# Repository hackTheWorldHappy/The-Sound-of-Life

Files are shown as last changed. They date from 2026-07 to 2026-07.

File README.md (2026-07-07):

# The Sound of Life 
janky_readmefalloutpic

A portable theremin using two time of flight sensors (ToFs) to detect pitch and volume. Also has a 1.8 TFT, which displays your live hand position relative to the sensors in order to make it easier to locate the proper pitch/volume.  

## CAD 
The stls can be found in the "CAD" folder of the repo, while the source files are publicly available at [this Onshape link](https://cad.onshape.com/documents/89ee755f4b78b4ae9f984f04/w/80025889893a9b576d4bea7a/e/b41170ff59c016846a22fa0f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).

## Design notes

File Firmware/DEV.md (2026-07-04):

because of bad network you need to increase network timeout:
C:\Users\<USER  >\.arduinoIDE\arduino-cli.yaml

add this:
network:
  connection_timeout: 300s

---

using Arduino and this board manager:

https://github.com/earlephilhower/arduino-pico/releases/download/global/package_rp2040_index.json

install libs

Tools > Usb Stack
use Adafruit one

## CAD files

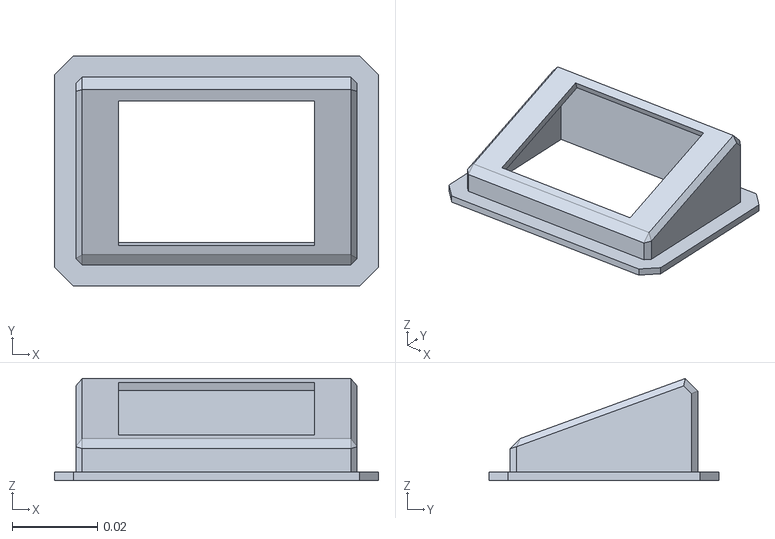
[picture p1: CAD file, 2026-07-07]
CAD/oled_cover.stl
0.076 x 0.054 x 0.0239

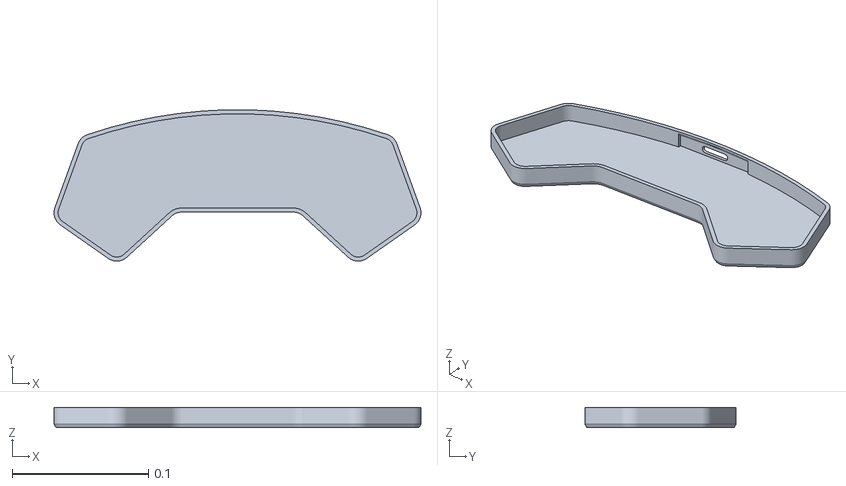
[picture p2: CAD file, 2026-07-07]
CAD/case_top.stl
0.269 x 0.111 x 0.015

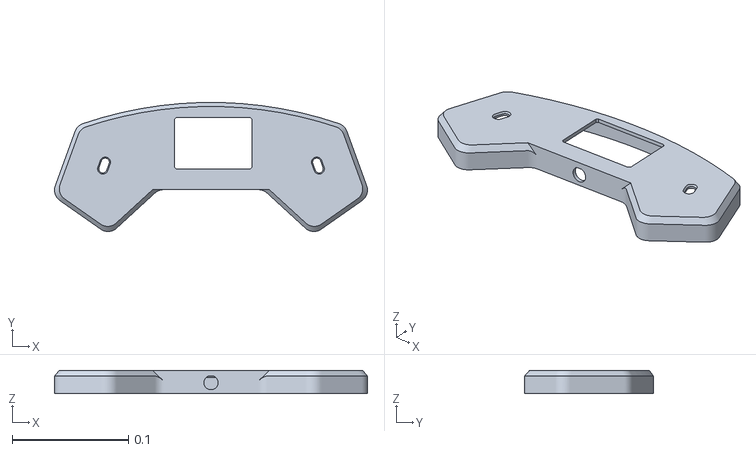
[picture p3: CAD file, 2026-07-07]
CAD/case_bottom.stl
0.269 x 0.111 x 0.02

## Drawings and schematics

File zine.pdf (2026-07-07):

# THE SOUND OF LIFE

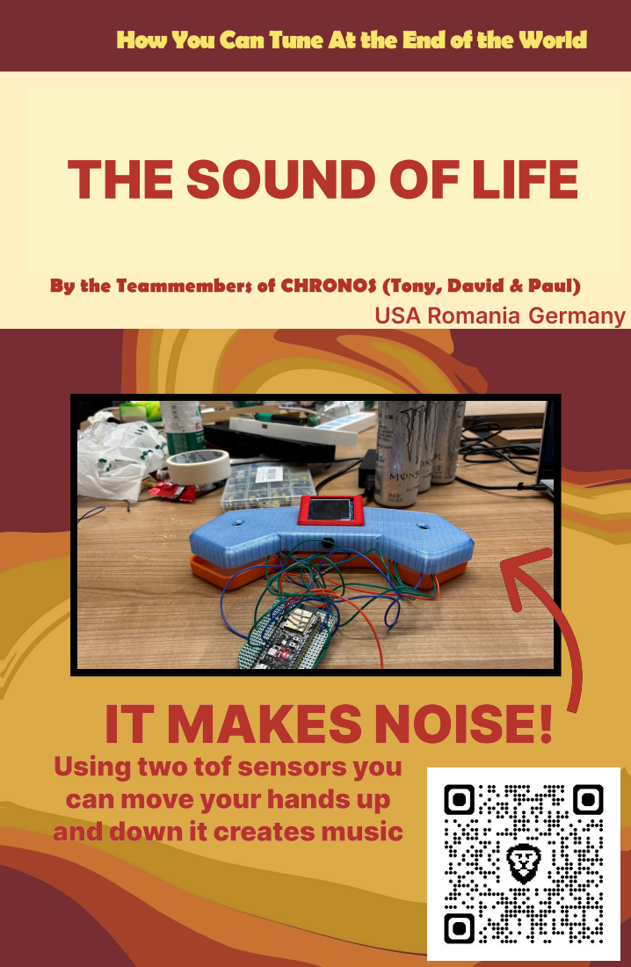
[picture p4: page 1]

USA Romania Germany

IT MAKES NOISE!
Using two tof sensors you
can move your hands up
and down it creates music

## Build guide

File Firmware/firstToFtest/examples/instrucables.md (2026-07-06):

his is a DIY project to create a MIDI Theremin . So lets go....
Supplies
Supplies
Supplies
Supplies

Arduino Leonardo

TOF sensor VL53LOX(2)

Berch pins(8)

Jumper wires

Micro USB cable
Step 1: WHY LEONARDO AND VL530LOX SENSOR
WHY LEONARDO AND VL530LOX SENSOR
WHY LEONARDO AND VL530LOX SENSOR

MIDI (Musical Instrument Digital Interface) devices are electronic instruments, controllers, and hardware that communicate musical performance data using the MIDI protocol (introduced in 1983). Instead of sending audio, MIDI sends digital instructions that describe music (e.g., notes, velocity, pitch bends, control changes).

The Arduino Leonardo is a microcontroller board based on the ATmega32u4. Unlike many other Arduino boards, it has built-in USB communication, allowing it to appear to a computer as a keyboard, mouse, or MIDI device without extra hardware. It features 20 digital I/O pins, 12 analog inputs, PWM outputs, a 16 MHz clock, and can be powered via USB or an external supply.

The reason for choosing VL530LOX Sensor are:

The VL53L0X time-of-flight distance sensor is far more suitable for building a theremin than traditional ultrasonic sensors because of its precision, speed, and stability. It measures distance using a tiny laser pulse, giving it millimeter-level accuracy and smooth, consistent readings. This is critical in a theremin, where even small fluctuations in distance translate into noticeable changes in pitch.

In contrast, ultrasonic sensors often produce jittery or unstable outputs, with limited resolution (around 1 cm) and slower response times, which can result in choppy or unpleasant sound transitions. The VL53L0X also features a very narrow sensing cone, allowing it to detect just the player’s hand without being confused by nearby objects, whereas ultrasonic sensors have a wide cone that easily picks up unintended reflections. Additionally, the VL53L0X is less affected by environmental factors like temperature, humidity, or surface texture, making its performance far more reliable. n.

Step 2: Test Run
Test Run

Here we tested the working of the concept using one sensor .

The code :

#include <Wire.h>

#include <Adafruit_VL53L0X.h>

// Create sensor object

Adafruit_VL53L0X lox = Adafruit_VL53L0X();

void setup() {

Serial.begin(115200);

while (!Serial); // Wait for Serial Monitor to open

Serial.println("VL53L0X Single Sensor Test");

// Initialize I²C

Wire.begin();

// Try to start sensor

if (!lox.begin()) {

Serial.println("Failed to find VL53L0X sensor!");

while (1); // Stop here if not found

}

Serial.println("VL53L0X sensor ready!");

}

void loop() {

VL53L0X_RangingMeasurementData_t measure;

// Perform a measurement

lox.rangingTest(&measure, false);

if (measure.RangeStatus != 4) { // Phase failures have error code 4

Serial.print("Distance: ");

Serial.print(measure.RangeMilliMeter);

Serial.println(" mm");

} else {

Serial.println("Out of range");

}

delay(200);

}
Step 3: CIRCUIT MAKING
CIRCUIT MAKING

LEONARDO HAS ONLY I^2C CHANNEL SO WHEN CONNECTING TWO VL530LOX WOULD BE RECOGNIZED AS ONE SENSOR RATHER THAN TWO SEPARATE ONES.

SO TO SOLVE THIS ISSUE WE HAVE INITIALIZE BOTH THE SENSORS IN SEPARETELY SO THAT THEY COULD HAVE THEIR UNIQUE I^2C ID.THEREFORE, THEIR XSHUT PINS ARE CONNECTED TO PIN 7,8 RESPECTIVELY SO ONE COULD BE MOMENTARILY SHUT TO INITIALIZE THE OTHER ONE .
Step 4: Coding

CODE TO INITIALIZE TWO VL530LOX SENSOR :

pinMode(XSHUT1, OUTPUT);

pinMode(XSHUT2, OUTPUT);

// Reset both

digitalWrite(XSHUT1, LOW);

digitalWrite(XSHUT2, LOW);

delay(10);

// Init Pitch sensor

digitalWrite(XSHUT1, HIGH);

delay(10);

if (!sensorPitch.begin(0x30)) {

Serial.println("Failed to detect Pitch sensor");

while (1);

}

// Init CC sensor

digitalWrite(XSHUT2, HIGH);

delay(10);

if (!sensorCC.begin(0x31)) {

Serial.println("Failed to detect CC sensor");

while (1);

}

Serial.println("Two VL53L0X ready!");

}

CODE OF PITCH BEND FUNCTION :

// Pitch bend calculation

float semitoneOffset = ((float)(pitchDist - pitchCenterDist) / (maxDistPitch - minDistPitch)) * pitchBendRangeSemitones * 2;

semitoneOffset = constrain(semitoneOffset, -pitchBendRangeSemitones, pitchBendRangeSemitones);

int bendValue = (int)(semitoneOffset * (8192.0 / pitchBendRangeSemitones));

bendValue = constrain(bendValue, -8192, 8191);

sendPitchBend(bendValue, midiChannel);

Serial.print("Distance: "); Serial.print(pitchDist);

Serial.print(" mm | Bend: "); Serial.println(bendValue); 

Code:
leothermin.ino

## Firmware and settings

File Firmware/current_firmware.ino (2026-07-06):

#include <Arduino.h>
#include <Wire.h>
#include <Adafruit_VL53L0X.h>
#include <SPI.h>
#include <Adafruit_GFX.h>
#include <Adafruit_ST7735.h>
#include <math.h>

// -------------------- PINS --------------------
#define PITCH_ADDR 0x30
#define VOLUME_ADDR 0x31

#define I2C_SDA 8
#define I2C_SCL 46

#define PITCH_XSHUT 4
#define VOLUME_XSHUT 5

#define TFT_CS 10
#define TFT_RST 9
#define TFT_DC 14

#define SCREEN_W 128
#define SCREEN_H 160

// -------------------- AUDIO STREAMING --------------------
#define SAMPLE_RATE 22050
#define FRAME_SAMPLES 64
#define SERIAL_BAUD 230400
#define SYNC_BYTE1 0xAA
#define SYNC_BYTE2 0x55
#define SINE_LUT_SIZE 256

// -------------------- SENSOR LIMITS --------------------
#define PITCH_MIN_MM 30
#define PITCH_MAX_MM 320
#define NOTE_MIN 48
#define NOTE_MAX 84

#define VOLUME_MIN_MM 30
#define VOLUME_MAX_MM 480
#define VOLUME_ON_MM 70
#define VOLUME_OFF_MM 110

// -------------------- GLOBALS --------------------
Adafruit_VL53L0X pitchSensor;
Adafruit_VL53L0X volumeSensor;
Adafruit_ST7735 tft = Adafruit_ST7735(TFT_CS, TFT_DC, TFT_RST);

bool sounding = false;
uint16_t lastValidPitchMm = 150;
uint16_t lastValidVolumeMm = 300;

float pitchSmooth = 0;

// Audio synthesis state (shared with ISR)
volatile float g_baseFreq = 440.0f;
volatile float g_velocity = 0.0f;
volatile bool g_sounding = false;

// Sine lookup table
int16_t sineLut[SINE_LUT_SIZE];

// Timer and frame buffer
hw_timer_t *audioTimer = NULL;
volatile int16_t frameBuffer[FRAME_SAMPLES];
volatile uint8_t frameIndex = 0;
volatile bool frameReady = false;

// Phase accumulators for 3 oscillators
volatile uint32_t phase1 = 0, phase2 = 0, phase3 = 0;
volatile uint32_t phaseInc1 = 0, phaseInc2 = 0, phaseInc3 = 0;

// -------------------- HELPERS --------------------
int noteToFreq(int note) {
	return (int)(440.0 * pow(2.0, (note - 69) / 12.0));
}

int mapPitchToNote(uint16_t mm) {
	return map(mm, PITCH_MIN_MM, PITCH_MAX_MM, NOTE_MIN, NOTE_MAX);
}

int mapVolumeToVelocity(uint16_t mm) {
	if (mm < VOLUME_ON_MM) return 0;
	if (mm > VOLUME_MAX_MM) return 127;
	return map(mm, VOLUME_ON_MM, VOLUME_MAX_MM, 0, 127);
}

// Fast sine from lookup table (linear interpolation)
inline int16_t sineLerp(uint32_t phase) {
	uint16_t idx = phase >> 24;
	uint8_t frac = (phase >> 16) & 0xFF;
	int16_t a = sineLut[idx];
	int16_t b = sineLut[(idx + 1) & (SINE_LUT_SIZE - 1)];
	return a + ((int32_t)(b - a) * frac >> 8);
}

// -------------------- AUDIO ISR --------------------
void IRAM_ATTR onAudioTimer() {
	if (!g_sounding || g_velocity <= 0.0f) {
		frameBuffer[frameIndex++] = 0;
		if (frameIndex >= FRAME_SAMPLES) {
			frameIndex = 0;
			frameReady = true;
		}
		return;
	}

	phase1 += phaseInc1;
	phase2 += phaseInc2;
	phase3 += phaseInc3;

	int32_t sum = sineLerp(phase1) + sineLerp(phase2) + sineLerp(phase3);
	int16_t sample = (int32_t)(sum * g_velocity * 0.33333f * 32767.0f) >> 15;

	frameBuffer[frameIndex++] = sample;

	if (frameIndex >= FRAME_SAMPLES) {
		frameIndex = 0;
		frameReady = true;
	}
}

// -------------------- SERIAL FRAMING --------------------
void sendFrame() {
	if (Serial.availableForWrite() < FRAME_SAMPLES * 2 + 5) return;

	uint8_t checksum = 0;
	Serial.write(SYNC_BYTE1);
	Serial.write(SYNC_BYTE2);
	Serial.write(FRAME_SAMPLES);
	checksum ^= SYNC_BYTE1;
	checksum ^= SYNC_BYTE2;
	checksum ^= FRAME_SAMPLES;

	for (uint8_t i = 0; i < FRAME_SAMPLES; i++) {
		uint8_t lo = frameBuffer[i] & 0xFF;
		uint8_t hi = (frameBuffer[i] >> 8) & 0xFF;
		Serial.write(lo);
		Serial.write(hi);
		checksum ^= lo;
		checksum ^= hi;
	}
	Serial.write(checksum);
}

// -------------------- SENSOR --------------------
bool bringUpSensor(uint8_t xshutPin, uint8_t address, Adafruit_VL53L0X &sensor) {
	digitalWrite(xshutPin, HIGH);
	delay(10);
	return sensor.begin(address);
}

uint16_t readMm(Adafruit_VL53L0X &sensor) {
	VL53L0X_RangingMeasurementData_t m;
	sensor.rangingTest(&m, false);
	if (m.RangeStatus == 4) return 0;
	return m.RangeMilliMeter;
}

// -------------------- SETUP --------------------
void setup() {
	Serial.begin(SERIAL_BAUD);

	SPI.begin();

	tft.initR(INITR_GREENTAB);
	tft.fillScreen(ST77XX_BLACK);

	Wire.begin(I2C_SDA, I2C_SCL);

	pinMode(PITCH_XSHUT, OUTPUT);
	pinMode(VOLUME_XSHUT, OUTPUT);
	digitalWrite(PITCH_XSHUT, LOW);
	digitalWrite(VOLUME_XSHUT, LOW);
	delay(10);

	// Build sine lookup table
	for (int i = 0; i < SINE_LUT_SIZE; i++) {
		sineLut[i] = (int16_t)(sinf(2.0f * PI * i / SINE_LUT_SIZE) * 32767.0f);
	}

        // Configure audio timer (22050 Hz) - ESP32 Arduino core v3.x API
        audioTimer = timerBegin(1000000);  // 1 MHz base frequency
        timerAttachInterrupt(audioTimer, &onAudioTimer);
        timerAlarm(audioTimer, 1000000 / SAMPLE_RATE, true, 0);
        timerStart(audioTimer);

	if (!bringUpSensor(PITCH_XSHUT, PITCH_ADDR, pitchSensor)) {
		Serial.println("Pitch fail");
	}
	if (!bringUpSensor(VOLUME_XSHUT, VOLUME_ADDR, volumeSensor)) {
		Serial.println("Volume fail");
	}

	tft.setCursor(0, 0);
	tft.setTextColor(ST77XX_GREEN);
	tft.println("Theremin OK");
	delay(1000);
}

// -------------------- LOOP --------------------
void loop() {
    static uint32_t lastPitchRead = 0;
    static uint32_t lastVolumeRead = 0;
    static bool readPitch = true;
    uint32_t now = millis();

    // Stagger sensor reads to reduce peak current (50ms apart)
    if (readPitch && (now - lastPitchRead >= 50)) {
        uint16_t pitchMm = readMm(pitchSensor);
        if (pitchMm) lastValidPitchMm = pitchMm;
        lastPitchRead = now;
        readPitch = false;
    } else if (!readPitch && (now - lastVolumeRead >= 50)) {
        uint16_t volumeMm = readMm(volumeSensor);
        if (volumeMm) lastValidVolumeMm = volumeMm;
        lastVolumeRead = now;
        readPitch = true;
    }

    uint16_t pitchMm = lastValidPitchMm;
    uint16_t volumeMm = lastValidVolumeMm;

    int note = mapPitchToNote(pitchMm);
    int freq = noteToFreq(note);
    int velocity = mapVolumeToVelocity(volumeMm);

    // sound gate with hysteresis
    if (volumeMm > VOLUME_OFF_MM) sounding = true;
    else if (volumeMm < VOLUME_ON_MM) sounding = false;

    // smoothing pitch
    pitchSmooth = pitchSmooth * 0.85 + freq * 0.15;

    // Update ISR globals atomically
    noInterrupts();
    g_baseFreq = pitchSmooth;
    g_velocity = velocity / 127.0f;
    g_sounding = sounding;

    float phaseIncBase = g_baseFreq * (float)(1ULL << 32) / SAMPLE_RATE;
    phaseInc1 = (uint32_t)phaseIncBase;
    phaseInc2 = (uint32_t)(phaseIncBase * 1.01f);
    phaseInc3 = (uint32_t)(phaseIncBase * 0.5f);
    interrupts();

    // Send completed frames
    if (frameReady) {
        frameReady = false;
        sendFrame();
    }

    // Debug output (throttled)
    static uint32_t lastDebug = 0;
    if (millis() - lastDebug > 100) {
        Serial.print("freq ");
        Serial.print(freq);
        Serial.print(" vel ");
        Serial.println(velocity);
        lastDebug = millis();
    }
}

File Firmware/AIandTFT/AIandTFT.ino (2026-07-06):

#include <Arduino.h>
#include <Wire.h>
#include <Adafruit_VL53L0X.h>
#include <Adafruit_GFX.h>
#include <Adafruit_ST7735.h>
#include <SPI.h>
#include <Adafruit_TinyUSB.h>
#include <MIDI.h>


#define PITCH_ADDR 0x30
#define VOLUME_ADDR 0x31

#define I2C_SDA 8
#define I2C_SCL 9

#define PITCH_XSHUT 4
#define VOLUME_XSHUT 5

#define TFT_CS   6
#define TFT_DC   7
#define TFT_RST  15
#define TFT_SCK  16
#define TFT_MOSI 17

#define PITCH_MIN_MM 50
#define PITCH_MAX_MM 450
#define NOTE_MIN 48
#define NOTE_MAX 84
#define VOLUME_MIN_MM 30
#define VOLUME_MAX_MM 400

Adafruit_USBD_MIDI usb_midi;
MIDI_CREATE_INSTANCE(Adafruit_USBD_MIDI, usb_midi, MIDI);

Adafruit_VL53L0X pitchSensor;
Adafruit_VL53L0X volumeSensor;


// TFT
SPIClass tftSPI(FSPI);
Adafruit_ST7735 tft(&tftSPI, TFT_CS, TFT_DC, TFT_RST);

const int16_t SCREEN_W = 128;
const int16_t SCREEN_H = 160;
const int16_t CURSOR_ZONE_W = 14;              // left strip: "now" + hand arrow
const int16_t BARCODE_X = CURSOR_ZONE_W;
const int16_t BARCODE_W = SCREEN_W - CURSOR_ZONE_W;
GFXcanvas16 canvas(SCREEN_W, SCREEN_H);
const float PIXELS_PER_MS = 0.06f;


// Song Data, currently twinkle twinkle little star
struct SongNote {
  uint8_t note;
  uint16_t durationMs;
};

const SongNote song[] = {
  {60, 400}, {60, 400}, {67, 400}, {67, 400},
  {69, 400}, {69, 400}, {67, 800},
  {65, 400}, {65, 400}, {64, 400}, {64, 400},
  {62, 400}, {62, 400}, {60, 800},
};
const uint8_t songLength = sizeof(song) / sizeof(song[0]);

uint32_t songCumMs[sizeof(song) / sizeof(song[0]) + 1];
uint32_t totalSongMs = 0;
uint32_t songStartMs = 0;

uint32_t lastUpdateMs = 0;
uint32_t lastDisplayMs = 0;
bool noteHeld = false;
int heldNote = 0;


uint32_t lastUpdateMs = 0;
bool noteHeld = false;
int heldNote = 0;

//
//

bool initSensor(uint8_t xshutPin, uint8_t address, Adafruit_VL53L0X &sensor) {
	pinMode(xshutPin, OUTPUT);
	digitalWrite(xshutPin, LOW);
	delay(10);
	digitalWrite(xshutPin, HIGH);
	delay(10);
	return sensor.begin(address);
 }

uint16_t readMm(Adafruit_VL53L0X &sensor) {
	VL53L0X_RangingMeasurementData_t measurement;
	sensor.rangingTest(&measurement, false);
	if (measurement.RangeStatus == 4) {
		return 0;
	}
	return measurement.RangeMilliMeter;
}

int mapPitchToNote(uint16_t mm) {
	if (mm == 0) {
		return 60;
	}
	return (int)map(constrain((long)mm, (long)PITCH_MIN_MM, (long)PITCH_MAX_MM), PITCH_MIN_MM, PITCH_MAX_MM, NOTE_MAX, NOTE_MIN);
}

int mapPitchToBend(uint16_t mm) {
	if (mm == 0) {
		return 8192;
	}
	return (int)map(constrain((long)mm, (long)PITCH_MIN_MM, (long)PITCH_MAX_MM), PITCH_MIN_MM, PITCH_MAX_MM, 0, 16383);
}

byte mapVolumeToExpression(uint16_t mm) {
	if (mm == 0) {
		return 0;
	}
	return (byte)map(constrain((long)mm, (long)VOLUME_MIN_MM, (long)VOLUME_MAX_MM), VOLUME_MIN_MM, VOLUME_MAX_MM, 127, 0);
}

// given a target note, what mm should the hand be at
uint16_t noteToMm(uint8_t note) {
  int n = constrain((int)note, NOTE_MIN, NOTE_MAX);
  return (uint16_t)map(n, NOTE_MAX, NOTE_MIN, PITCH_MIN_MM, PITCH_MAX_MM);
}

// 
int16_t mmToY(uint16_t mm) {
  return (int16_t)map(constrain((long)mm, (long)PITCH_MIN_MM, (long)PITCH_MAX_MM),
                       PITCH_MIN_MM, PITCH_MAX_MM, 0, SCREEN_H - 1);
}


// Song helpers
void buildSongTiming() {
  songCumMs[0] = 0;
  for (uint8_t i = 0; i < songLength; i++) {
    songCumMs[i + 1] = songCumMs[i] + song[i].durationMs;
  }
  totalSongMs = songCumMs[songLength];
}

uint8_t noteAtTime(uint32_t t) {
  t %= totalSongMs;
  for (uint8_t i = 0; i < songLength; i++) {
    if (t < songCumMs[i + 1]) {
      return song[i].note;
    }
  }
  return song[songLength - 1].note;
}

// Display

void drawFrame(uint16_t handMm) {
  canvas.fillScreen(ST77XX_BLACK);

  uint32_t nowMs = (millis() - songStartMs) % totalSongMs;

  // Scrolling barcode: column 0 = "now"
  for (int16_t x = 0; x < BARCODE_W; x++) {
    uint32_t t = (nowMs + (uint32_t)(x / PIXELS_PER_MS)) % totalSongMs;
    uint8_t note = noteAtTime(t);
    uint16_t targetMm = noteToMm(note);
    int16_t y = mmToY(targetMm);
    uint16_t color = ST77XX_CYAN;
    canvas.fillRect(BARCODE_X + x, y - 1, 1, 3, color);
  }

  // "Now" reference line at the boundary between the cursor zone and barcode
  canvas.drawFastVLine(BARCODE_X, 0, SCREEN_H, ST77XX_YELLOW);

  // Current hand height, drawn as a right-pointing arrow in the left zone
  if (handMm > 0) {
    int16_t y = mmToY(handMm);
    canvas.fillTriangle(0, y - 4, 0, y + 4, CURSOR_ZONE_W - 2, y, ST77XX_RED);
  }

  tft.drawRGBBitmap(0, 0, canvas.getBuffer(), SCREEN_W, SCREEN_H);
}


void setup() {
	Serial.begin(115200);

	Wire.begin(I2C_SDA, I2C_SCL);

	if (!TinyUSBDevice.isInitialized()) {
		TinyUSBDevice.begin(0);
	}

	usb_midi.setStringDescriptor("Theremin MIDI");
	MIDI.begin(MIDI_CHANNEL_OMNI);

	if (TinyUSBDevice.mounted()) {
		TinyUSBDevice.detach();
		delay(10);
		TinyUSBDevice.attach();
	}

	if (!initSensor(PITCH_XSHUT, PITCH_ADDR, pitchSensor)) {
		while (1) {
			delay(1)
		}
	}

	if (!initSensor(VOLUME_XSHUT, VOLUME_ADDR, volumeSensor)) {
		while (1) {
			delay(1);
		}
	}
  tftSPI.begin(TFT_SCK, -1, TFT_MOSI, TFT_CS);
  tft.initR(INITR_BLACKTAB);
  tft.setRotation(0);
  tft.fillScreen(ST77XX_BLACK);
  buildSongTiming();
  songStartMs = millis();

}

void loop() {
#ifdef TINYUSB_NEED_POLLING_TASK
	TinyUSBDevice.task();
#endif

   uint32_t nowMillis = millis();
	if (nowMillis() - lastUpdateMs < 25) {
		return;
	}
	lastUpdateMs = nowMillis();

	const bool midiReady = TinyUSBDevice.mounted();
	const uint16_t pitchMm = readMm(pitchSensor);
	const uint16_t volumeMm = readMm(volumeSensor);
	const bool sounding = volumeMm >= 120;
	const int note = mapPitchToNote(pitchMm);
	const int bend = mapPitchToBend(pitchMm);
	const byte expression = mapVolumeToExpression(volumeMm);

	if (midiReady) {
		if (sounding) {
			if (!noteHeld) {
				MIDI.sendNoteOn(note, 100, 1);
				noteHeld = true;
				heldNote = note;
			} else if (heldNote != note) {
				MIDI.sendNoteOff(heldNote, 0, 1);
				MIDI.sendNoteOn(note, 100, 1);
				heldNote = note;
			}

			MIDI.sendPitchBend(bend, 1);
			MIDI.sendControlChange(11, expression, 1);
		} else if (noteHeld) {
			MIDI.sendNoteOff(heldNote, 0, 1);
			noteHeld = false;
			heldNote = 0;
		}
	} else {
		noteHeld = false;
		heldNote = 0;
	}

	MIDI.read();
  if (nowMillis - lastDisplayMs >= 50) {
    lastDisplayMs = nowMillis;
    drawFrame(pitchMm);
    }
  }
}

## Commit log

2026-07-04 Added sensor initialization and integrated MIDI note/pitch bend messaging based on sensor readings. Tried creating OLED display rendering. added cavemen.md for less token usage.
2026-07-05 moved in git fixed
    [firstAcctualCode.ino, firstToFtest.ino]
2026-07-06 esp sensor disconnect/reconnect
2026-07-07 added cad, update readme a bit
    [case_bottom.stl, case_top.stl, oled_cover.stl]
